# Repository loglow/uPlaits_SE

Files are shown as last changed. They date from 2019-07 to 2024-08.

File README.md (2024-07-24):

# µPlaits SE (uPlaits, microPlaits) Eurorack [Rev C]

## 8HP Eurorack module | Macro-oscillator

[µPlaits SE](http://uplaits-se.com) is a voltage-controlled sound source offering direct access to a large palette of easily tweakable raw sonic material generated by models spanning a wide range of synthesis techniques.

This re-engineered Eurorack module miniaturizes and redesigns the original [Mutable Instruments Plaits](https://mutable-instruments.net/modules/plaits/), reducing its size from 12HP to 8HP and reworking its front panel layout.

Fully compatible with upstream Plaits firmware. Includes power cable, mounting hardware, and a one-year warranty. Designed and built with care by [Tall Dog Electronics](http://tall-dog.com) in Western Massachusetts. Licensed [CC BY-SA 4.0](https://creativecommons.org/licenses/by-sa/4.0/) open source hardware.

- **Height:** 3U (128.5 mm)
- **Width:** 8HP (40.3 mm)
- **Depth:** 43 mm (with power)
- **+12V:** 50 mA (average)
- **-12V:** 5 mA (average)

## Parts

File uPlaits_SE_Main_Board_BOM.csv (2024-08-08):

Ref | Qty | Desc | Mfg | MPN
C1 C2 C3 C4 C8 C9 C32 C35 | 8 | CAP CER 1000PF 50V C0G/NP0 0603 | Murata Electronics | GRM1885C1H102JA01D
C5 C10 C11 C13 C14 C15 C16 C18 C19 C22 C25 C27 C28 C29 C30 C31 C34 C37 C39 C41 C43 C47 | 22 | CAP CER 0.1UF 25V X7R 0603 | Murata Electronics | GCM188R71E104KA57D
C6 C7 C33 C36 | 4 | CAP CER 100PF 50V C0G/NP0 0603 | Vishay Vitramon | VJ0603A101JXACW1BC
C12 C42 C44 C46 C50 | 5 | CAP ALUM 10UF 20% 25V SMD | Würth Elektronik | 865230440002
C17 C21 C24 C26 C48 | 5 | CAP CER 1UF 25V X5R 0603 | YAGEO | CC0603KRX5R8BB105
C20 C23 | 2 | CAP CER 20PF 50V C0G/NP0 0603 | Samsung Electro-Mechanics | CL10C200JB8NNNC
C38 C40 | 2 | CAP CER 2.2UF 25V X5R 0805 | Samsung Electro-Mechanics | CL21A225KAFNNNG
C45 C52 | 2 | CAP ALUM 22UF 20% 25V SMD | Würth Elektronik | 865230443003
C49 C51 C53 | 3 | CAP CER 22UF 25V X5R 1206 | Samsung Electro-Mechanics | CL31A226KAHNNNE
D1 D2 D3 D4 D5 D6 D7 D8 | 8 | VARISTOR 65V 0603 | EPCOS - TDK Electronics | B72500D0160H060
D9 | 1 | DIODE ARR SCHOTT 30V 200MA SOT23 | onsemi | BAT54SLT1G
D10 D11 | 2 | DIODE SCHOTTKY 40V 1A SOD123 | Diodes Incorporated | 1N5819HW-7-F
H1 H2 H3 H4 H5 | 5 | FEMALE HEADER VERTICAL THROUGH H | SUPERIOR TECH | FHMD-DA010G1NBON-B
H6 | 1 | DO NOT POPULATE | DNP | DNP
H7 | 1 | CONN HEADER VERT 10POS 1.27MM | CNC Tech | 3220-10-0100-00
H8 | 1 | CONN HEADER VERT 10POS 2.54MM | On Shore Technology Inc. | 302-S101
L1 L2 L3 L5 | 4 | FERRITE BEAD 1K OHM 0603 1LN | Würth Elektronik | 742792664
L4 | 1 | FIXED IND 33UH 190MA 2.6 OHM SMD | TDK Corporation | MLZ2012M330WT000
R1 R6 R7 R12 R13 R18 R19 R24 | 8 | RES SMD 100K OHM 1% 1/10W 0603 | Panasonic Electronic Components | ERJ-3EKF1003V
R2 R8 R23 | 3 | RES SMD 120K OHM 1% 1/10W 0603 | Panasonic Electronic Components | ERJ-3EKF1203V
R3 R9 R22 | 3 | RES SMD 20K OHM 1% 1/10W 0603 | Panasonic Electronic Components | ERJ-3EKF2002V
R4 R10 R16 R21 R39 R42 | 6 | RES SMD 33K OHM 1% 1/10W 0603 | Panasonic Electronic Components | ERJ-3EKF3302V
R5 R14 R17 | 3 | RES SMD 200K OHM 1% 1/10W 0603 | Panasonic Electronic Components | ERJ-3EKF2003V
R11 | 1 | RES SMD 140K OHM 1% 1/10W 0603 | Panasonic Electronic Components | ERJ-3EKF1403V
R15 | 1 | RES SMD 56K OHM 1% 1/10W 0603 | Panasonic Electronic Components | ERJ-3EKF5602V
R20 | 1 | RES SMD 110K OHM 1% 1/10W 0603 | Panasonic Electronic Components | ERJ-3EKF1103V
R25 R27 R28 R29 R30 R31 R33 R38 R41 | 9 | RES SMD 10K OHM 1% 1/10W 0603 | Panasonic Electronic Components | ERJ-3EKF1002V
R26 R32 R34 R35 | 4 | RES SMD 100 OHM 1% 1/10W 0603 | Panasonic Electronic Components | ERJ-3EKF1000V
R36 R43 | 2 | RES 1K OHM 1% 1/4W 0603 | Rohm Semiconductor | ESR03EZPF1001
R37 R40 R44 | 3 | RES SMD 2.2K OHM 1% 1/10W 0603 | Panasonic Electronic Components | ERJ-3EKF2201V
U1 U2 | 2 | IC OPAMP GP 4 CIRCUIT 14TSSOP | Microchip Technology | MCP6004T-I/ST
U3 | 1 | IC LED DRIVER LINEAR 35MA 24SSOP | Texas Instruments | TLC59281DBQR
U4 | 1 | IC MCU 32BIT 256KB FLASH 48LQFP | STMicroelectronics | STM32F373CCT6
U5 | 1 | IC OPAMP JFET 2 CIRCUIT 8SOIC | Texas Instruments | TL072CDR
U6 | 1 | IC DAC 16/24/32BIT 384K 20TSSOP | Texas Instruments | PCM5100APWR
U7 | 1 | IC VREF SHUNT 0.5% SOT23-3 | Texas Instruments | LM4040C10IDBZR
U8 | 1 | IC REG LINEAR 3.3V 100MA SOT23-5 | STMicroelectronics | LD2981ABM33TR
U9 | 1 | DC DC CONVERTER 3.3V 2W | Recom Power | R-78E3.3-0.5
X1 | 1 | CRYSTAL 8.0000MHZ 18PF SMD | Abracon LLC | ABMM2-8.000MHZ-E2-T

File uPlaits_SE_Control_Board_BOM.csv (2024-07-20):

Ref | Qty | Desc | Mfg | MPN
D1 D2 D3 D4 D5 D6 D7 D8 | 8 | LED GREEN/RED DIFF T-3MM TRI T/H | Lumex Opto/Components Inc. | SSL-LX3059IGW-CA
H1 H2 H3 H4 H5 | 5 | CONN HEADER VERT 10POS 2.54MM | Amphenol ICC (FCI) | 67997-210HLF
J1 J2 J3 J4 J5 J6 J7 J8 J9 J10 | 10 | 3.5MM JACK VERTICAL PCB MOUNT | Wenzhou QingPu | WQP-WQP518MA
P1 P2 P3 P5 | 4 | POT 9MM LINEAR B10K WHITE LINE | Song Huei | R0904N-B10K,L-25KQ/LWS
P4 P6 P7 | 3 | POT 9MM LINEAR B10K WHITE LINE CENTER DETENT | Song Huei | R0904N-B10K,L-25KQ/LWS/CC
S1 S2 | 2 | SWITCH TACTILE SPST-NO 0.05A 12V | E-Switch | TL1105DF160Q

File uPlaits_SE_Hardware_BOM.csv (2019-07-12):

Description | Quantity
Thonkiconn Knurled Nut, Steel, M6 | 10
Threaded Hex Standoff, Brass, M2.5 x 11 mm | 2
Standoff Screw, Button Head, Hex Socket, M2.5 x 6 mm | 4

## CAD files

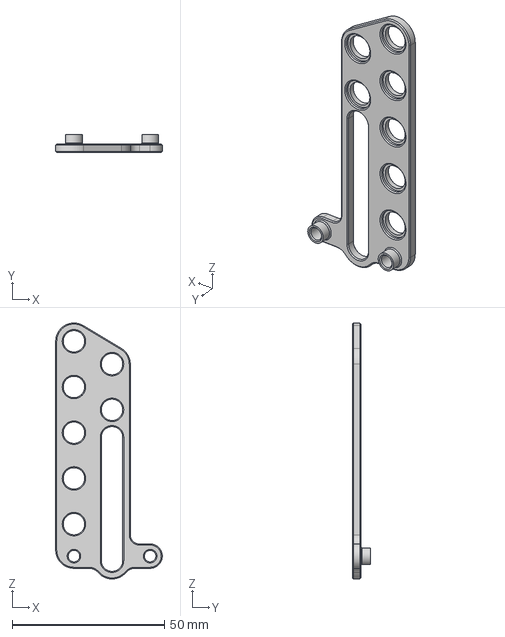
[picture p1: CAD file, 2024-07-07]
uPlaits_SE_Assembly_Spacer.step
35.0 x 6.00 x 84.0 mm

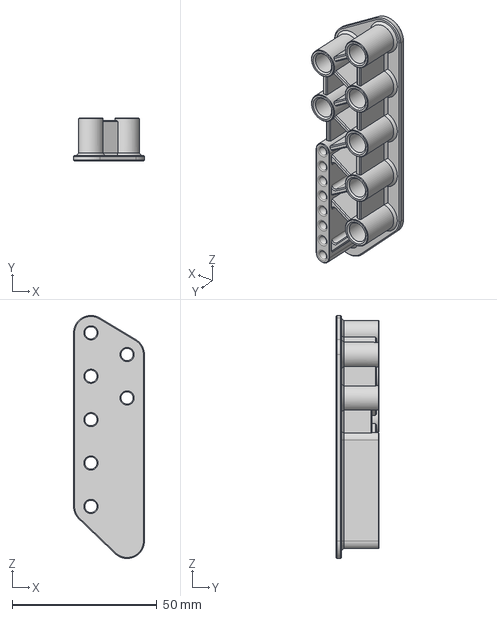
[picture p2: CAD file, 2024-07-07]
uPlaits_SE_Assembly_Cap.step
24.5 x 15.0 x 84.0 mm

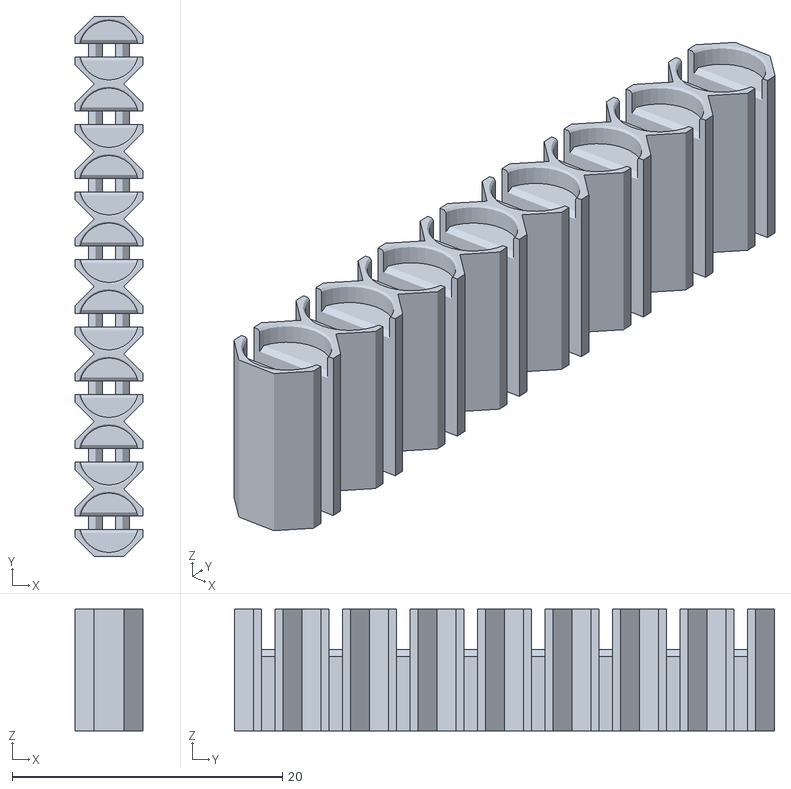
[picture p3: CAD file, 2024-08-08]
uPlaits_SE_LED_Spacer.stl
5.00 x 40.0 x 9.00

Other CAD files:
uPlaits_SE_Assembly_Cap.stl
uPlaits_SE_Assembly_Spacer.stl
uPlaits_SE_Model.skp

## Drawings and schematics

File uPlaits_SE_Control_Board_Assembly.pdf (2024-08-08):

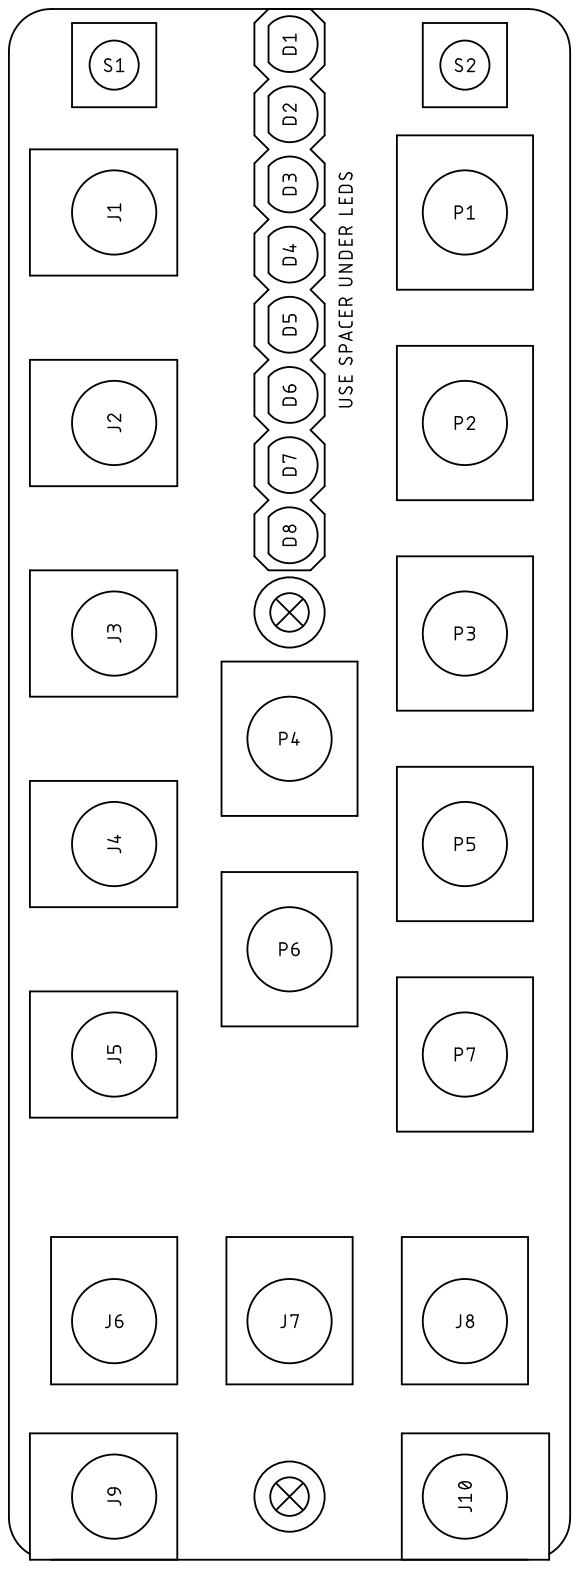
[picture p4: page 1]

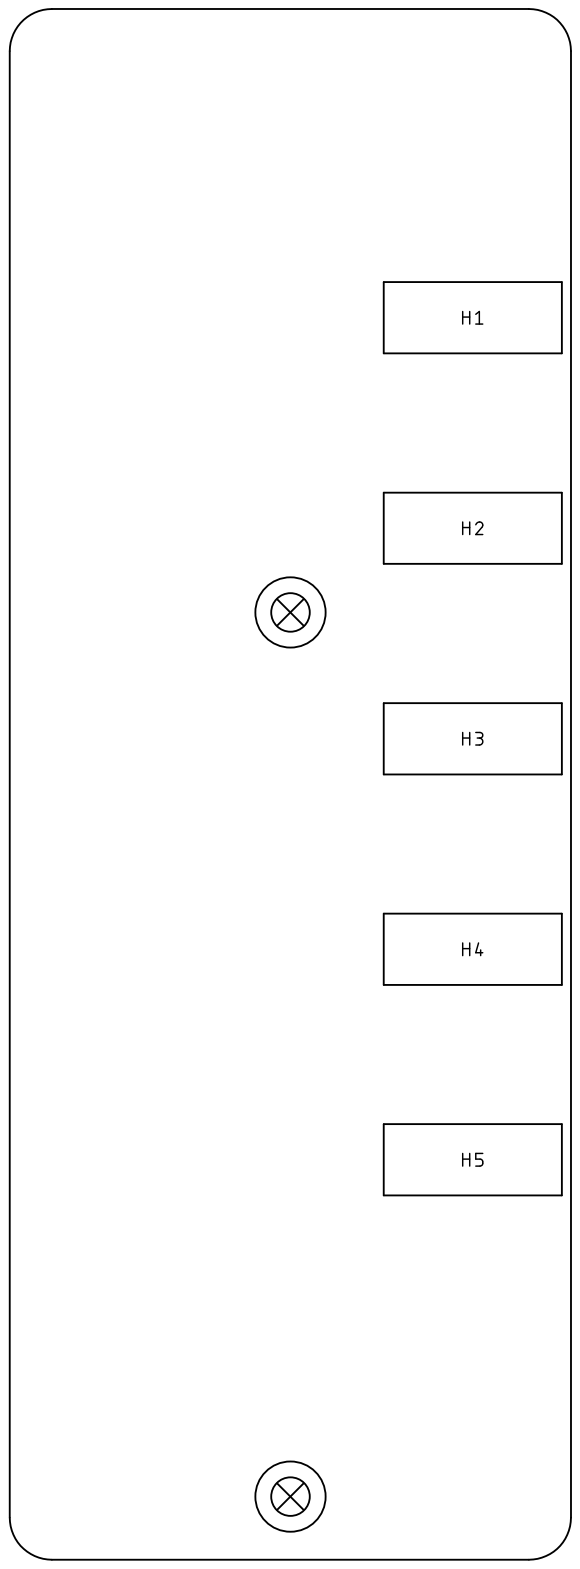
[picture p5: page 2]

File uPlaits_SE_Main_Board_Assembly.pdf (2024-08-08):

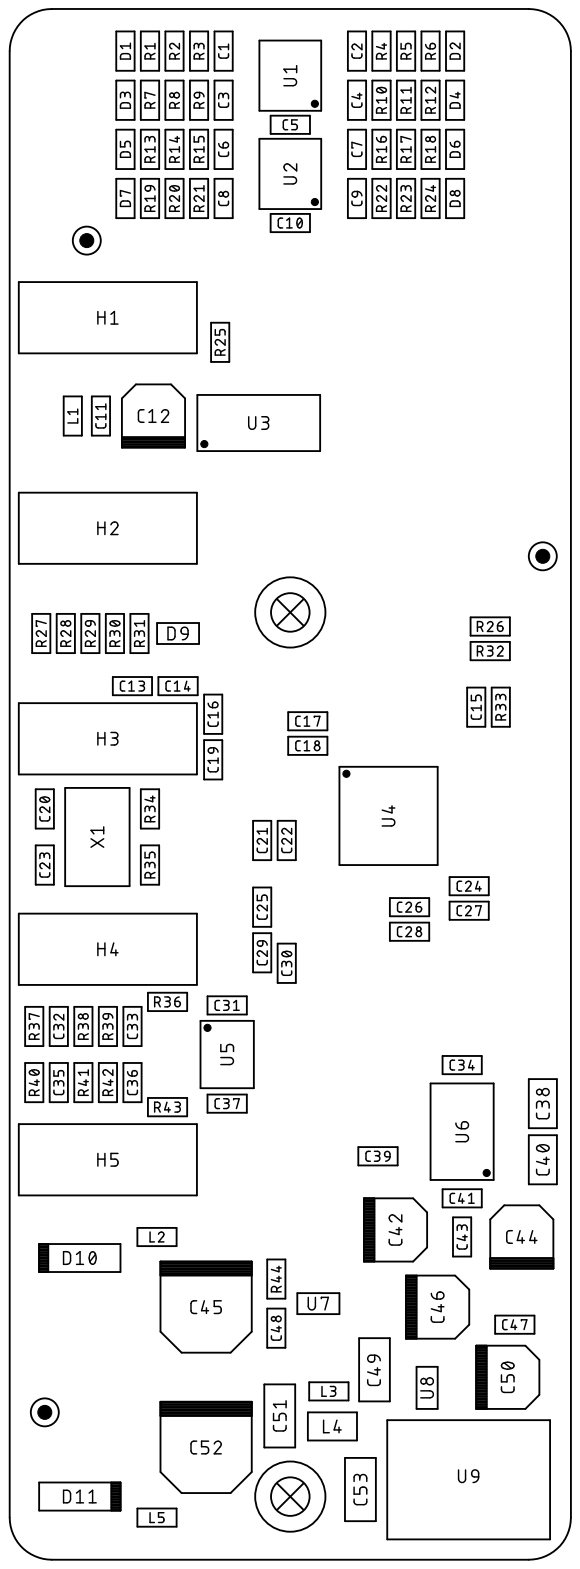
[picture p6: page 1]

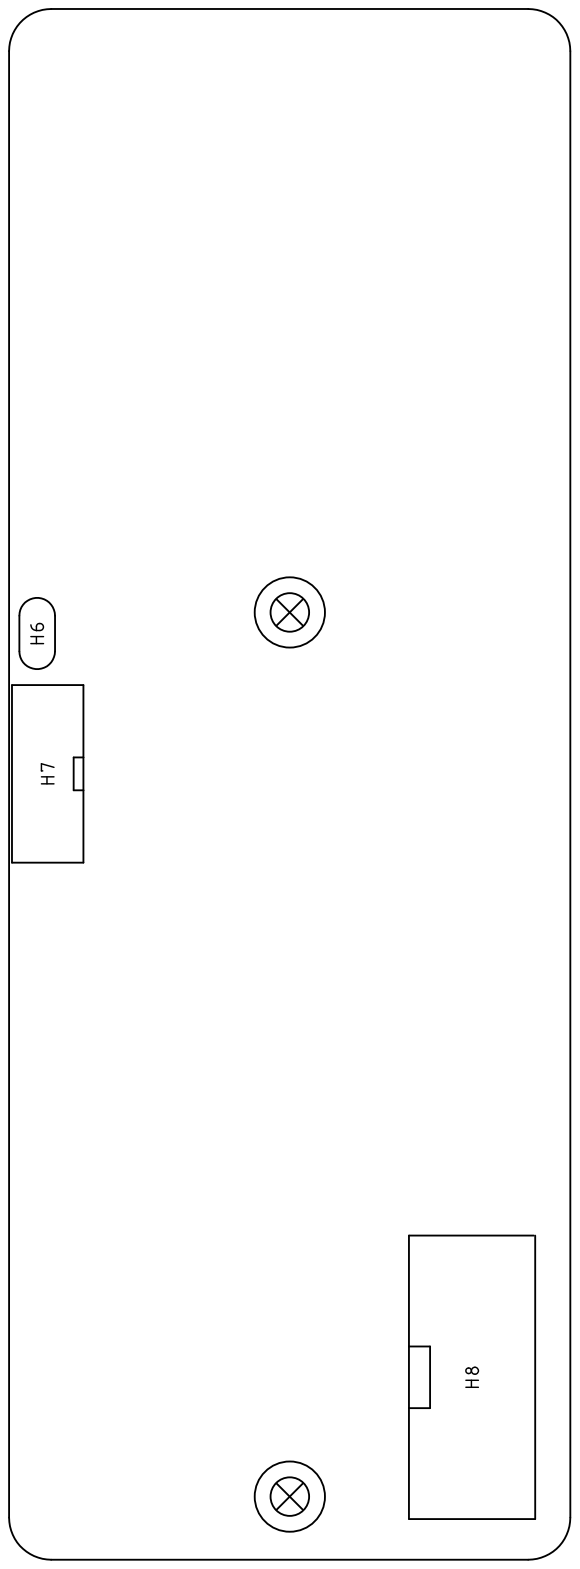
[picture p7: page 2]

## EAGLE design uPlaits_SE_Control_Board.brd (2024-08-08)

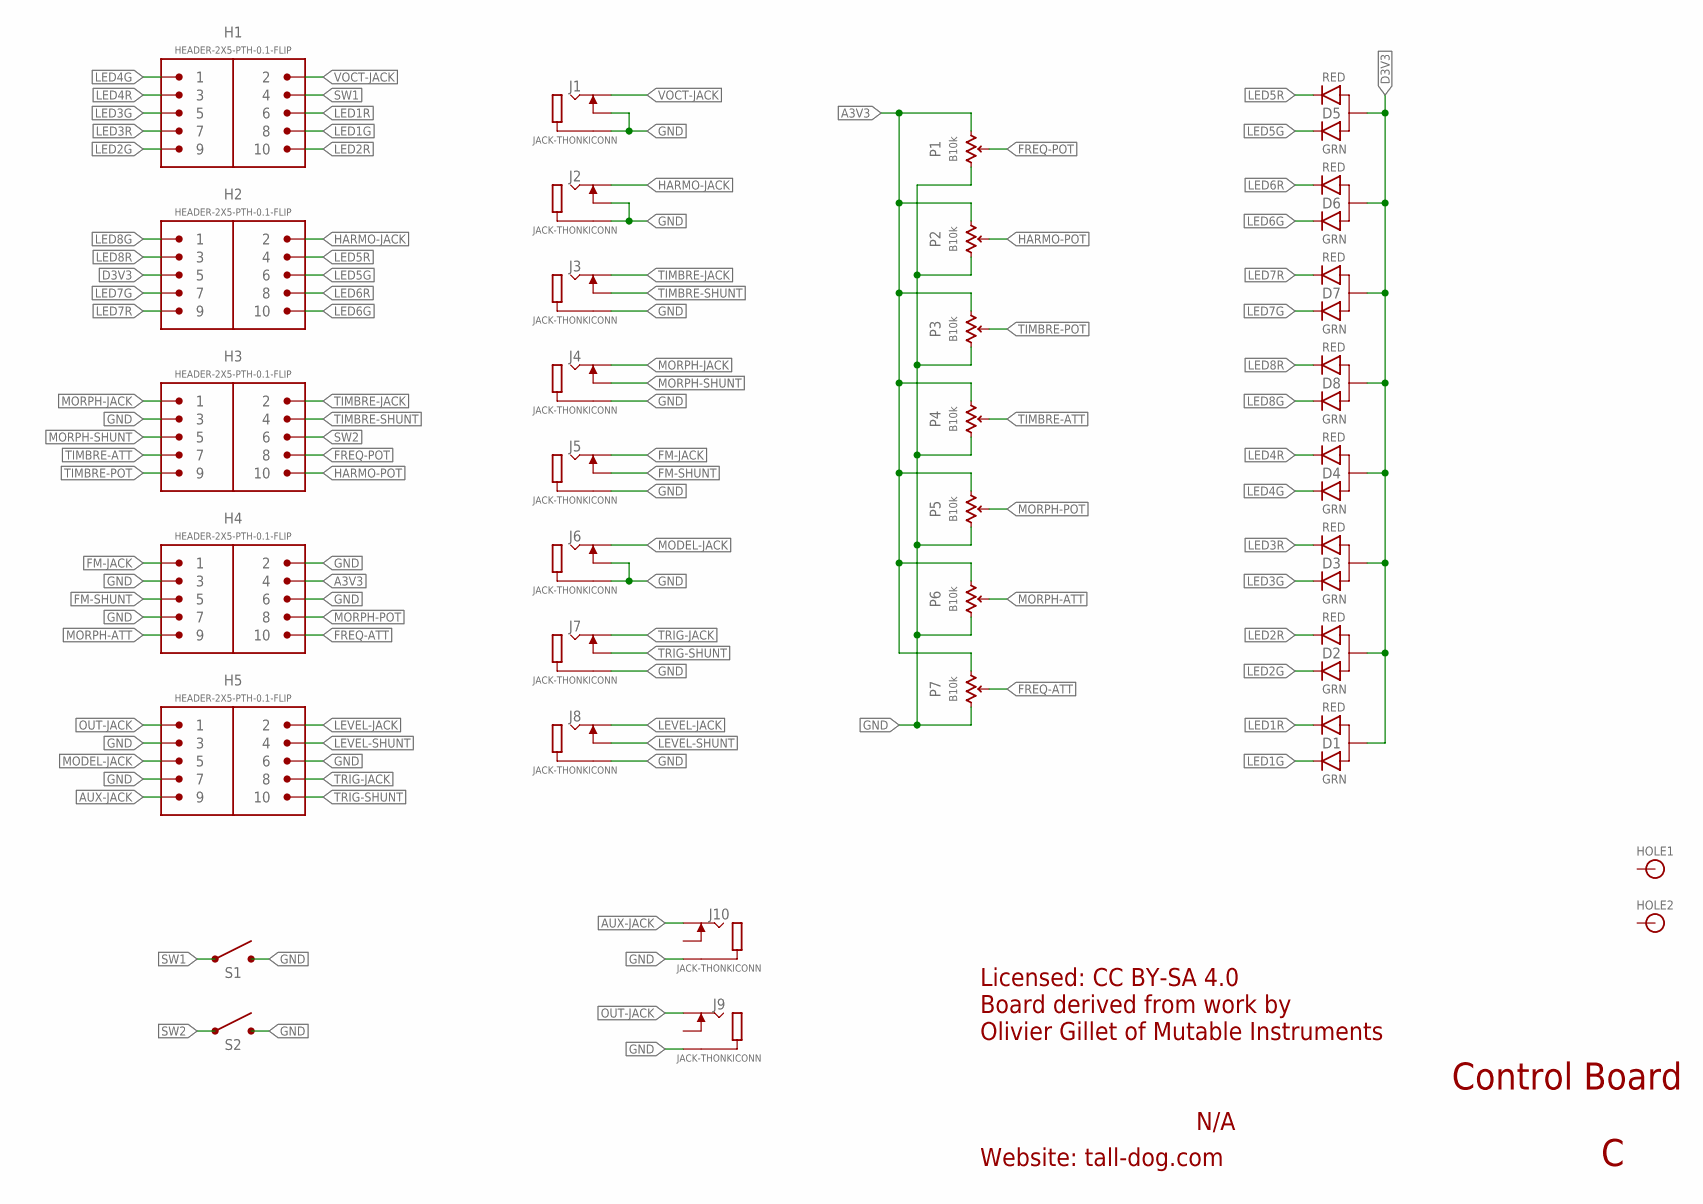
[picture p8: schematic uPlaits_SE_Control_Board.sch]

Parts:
D1, D2, D3, D4, D5, D6, D7, D8: LED-DUAL-PTH; LED-T1-3
H1, H2, H3, H4, H5: HEADER-2X5-PTH-0.1-FLIP; PTH-0.1-2X5-FLIP
HOLE1, HOLE2: HOLE; HOLE-M2.5
J1, J2, J3, J4, J5, J6, J7, J8, J9, J10: JACK-THONKICONN; THONKICONN
P1, P2, P3, P4, P5, P6, P7: B10k; POT-SONG-9MM
S1, S2: SPST-PTH; TL1105

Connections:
A3V3: H4.4, P1.P$1 (E), P2.P$1 (E), P3.P$1 (E), P4.P$1 (E), P5.P$1 (E), P6.P$1 (E), P7.P$1 (E)
AUX-JACK: H5.9, J10.P3 (3)
D3V3: D1.2 (A), D2.2 (A), D3.2 (A), D4.2 (A), D5.2 (A), D6.2 (A), D7.2 (A), D8.2 (A), H2.5
FM-JACK: H4.1, J5.P3 (3)
FM-SHUNT: H4.5, J5.P2 (2)
FREQ-ATT: H4.10, P7.P$2 (S)
FREQ-POT: H3.8, P1.P$2 (S)
GND: H3.3, H4.2, H4.3, H4.6, H4.7, H5.3, H5.6, H5.7, J1.P1 (1), J1.P2 (2), J2.P1 (1), J2.P2 (2), J3.P1 (1), J4.P1 (1), J5.P1 (1), J6.P1 (1), J6.P2 (2), J7.P1 (1), J8.P1 (1), J9.P1 (1), J10.P1 (1), P1.P$3 (A), P2.P$3 (A), P3.P$3 (A), P4.P$3 (A), P5.P$3 (A), P6.P$3 (A), P7.P$3 (A), S1.3 (2), S1.4 (2), S2.3 (2), S2.4 (2)
HARMO-JACK: H2.2, J2.P3 (3)
HARMO-POT: H3.10, P2.P$2 (S)
LED1G: D1.3 (GRN), H1.8
LED1R: D1.1 (RED), H1.6
LED2G: D2.3 (GRN), H1.9
LED2R: D2.1 (RED), H1.10
LED3G: D3.3 (GRN), H1.5
LED3R: D3.1 (RED), H1.7
LED4G: D4.3 (GRN), H1.1
LED4R: D4.1 (RED), H1.3
LED5G: D5.3 (GRN), H2.6
LED5R: D5.1 (RED), H2.4
LED6G: D6.3 (GRN), H2.10
LED6R: D6.1 (RED), H2.8
LED7G: D7.3 (GRN), H2.7
LED7R: D7.1 (RED), H2.9
LED8G: D8.3 (GRN), H2.1
LED8R: D8.1 (RED), H2.3
LEVEL-JACK: H5.2, J8.P3 (3)
LEVEL-SHUNT: H5.4, J8.P2 (2)
MODEL-JACK: H5.5, J6.P3 (3)
MORPH-ATT: H4.9, P6.P$2 (S)
MORPH-JACK: H3.1, J4.P3 (3)
MORPH-POT: H4.8, P5.P$2 (S)
MORPH-SHUNT: H3.5, J4.P2 (2)
OUT-JACK: H5.1, J9.P3 (3)
SW1: H1.4, S1.1, S1.2 (1)
SW2: H3.6, S2.1, S2.2 (1)
TIMBRE-ATT: H3.7, P4.P$2 (S)
TIMBRE-JACK: H3.2, J3.P3 (3)
TIMBRE-POT: H3.9, P3.P$2 (S)
TIMBRE-SHUNT: H3.4, J3.P2 (2)
TRIG-JACK: H5.8, J7.P3 (3)
TRIG-SHUNT: H5.10, J7.P2 (2)
VOCT-JACK: H1.2, J1.P3 (3)

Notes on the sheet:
Licensed: CC BY-SA 4.0 Board derived from work by Olivier Gillet of Mutable Instruments
Website: tall-dog.com
N/A
Control Board

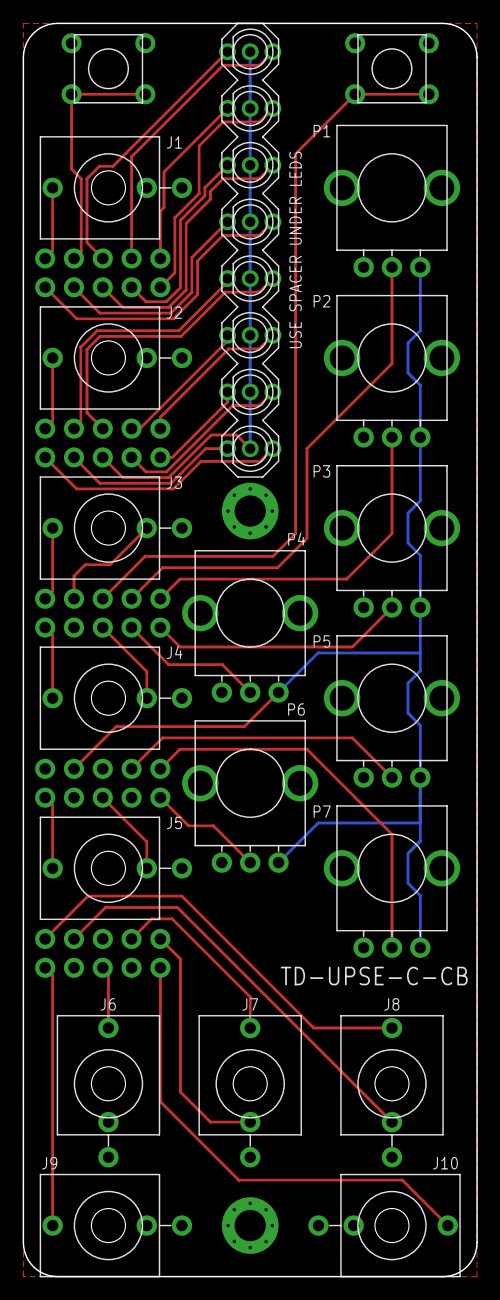
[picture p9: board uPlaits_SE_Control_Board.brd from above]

Board: 2 copper layers, 40.0 x 110.5 mm, 35 parts (0 on the bottom side), 43 nets.

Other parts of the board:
U$1: LED-SPACER

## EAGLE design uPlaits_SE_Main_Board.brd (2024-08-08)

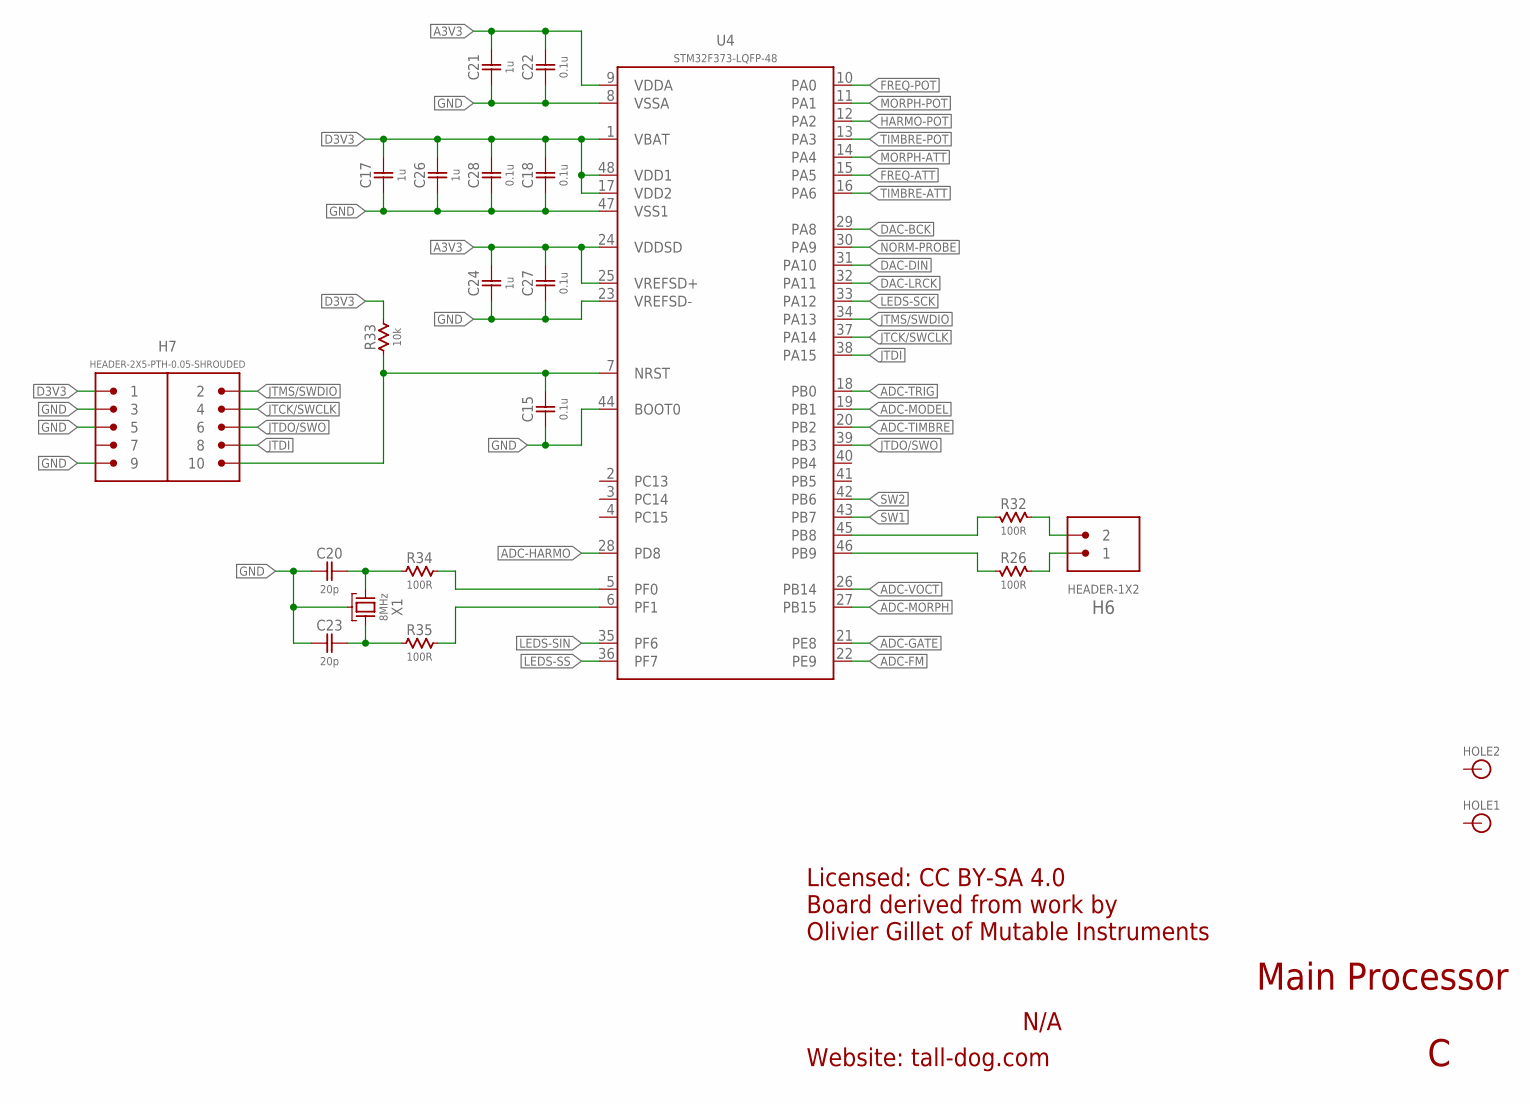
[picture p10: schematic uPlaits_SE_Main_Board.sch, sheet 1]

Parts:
C15, C18, C22, C27, C28: 0.1u; 0603-NP
C17, C21, C24, C26: 1u; 0603-NP
C20, C23: 20p; 0603-NP
H6: HEADER-1X2; PTH-0.1-1X2
H7: HEADER-2X5-PTH-0.05-SHROUDED; PTH-0.05-2X5-SHROUDED
HOLE1, HOLE2: HOLE; HOLE-M2.5
R26, R32, R34, R35: 100R; 0603-NP
R33: 10k; 0603-NP
U4: STM32F373-LQFP-48; LQFP-48
X1: 8MHz; CRYSTAL-ABMM2

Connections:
A3V3: C21.2, C22.2, C24.2, C27.2, U4.9 (VDDA), U4.24 (VDDSD), U4.25 (VREFSD+); also elsewhere on the board
ADC-FM: U4.22 (PE9); also elsewhere on the board
ADC-GATE: U4.21 (PE8); also elsewhere on the board
ADC-HARMO: U4.28 (PD8); also elsewhere on the board
ADC-MODEL: U4.19 (PB1); also elsewhere on the board
ADC-MORPH: U4.27 (PB15); also elsewhere on the board
ADC-TIMBRE: U4.20 (PB2); also elsewhere on the board
ADC-TRIG: U4.18 (PB0); also elsewhere on the board
ADC-VOCT: U4.26 (PB14); also elsewhere on the board
D3V3: C17.2, C18.2, C26.2, C28.2, H7.1, R33.2, U4.1 (VBAT), U4.17 (VDD2), U4.48 (VDD1); also elsewhere on the board
DAC-BCK: U4.29 (PA8); also elsewhere on the board
DAC-DIN: U4.31 (PA10); also elsewhere on the board
DAC-LRCK: U4.32 (PA11); also elsewhere on the board
FREQ-ATT: U4.15 (PA5); also elsewhere on the board
FREQ-POT: U4.10 (PA0); also elsewhere on the board
GND: C15.1, C17.1, C18.1, C20.1, C21.1, C22.1, C23.1, C24.1, C26.1, C27.1, C28.1, H7.3, H7.5, H7.9, U4.8 (VSSA), U4.23 (VREFSD-), U4.44 (BOOT0), U4.47 (VSS1), X1.2 (G), X1.4 (G); also elsewhere on the board
HARMO-POT: U4.12 (PA2); also elsewhere on the board
JTCK/SWCLK: H7.4, U4.37 (PA14)
JTDI: H7.8, U4.38 (PA15)
JTDO/SWO: H7.6, U4.39 (PB3)
JTMS/SWDIO: H7.2, U4.34 (PA13)
LEDS-SCK: U4.33 (PA12); also elsewhere on the board
LEDS-SIN: U4.35 (PF6); also elsewhere on the board
LEDS-SS: U4.36 (PF7); also elsewhere on the board
MORPH-ATT: U4.14 (PA4); also elsewhere on the board
MORPH-POT: U4.11 (PA1); also elsewhere on the board
unnamed: C20.2, R34.1, X1.3 (2)
unnamed: C23.2, R35.1, X1.1
unnamed: R34.2, U4.5 (PF0)
unnamed: R35.2, U4.6 (PF1)
NORM-PROBE: U4.30 (PA9); also elsewhere on the board
RESET: C15.2, H7.10, R33.1, U4.7 (NRST)
RX: H6.1, R26.1
RX1: R26.2, U4.46 (PB9)
SW1: U4.43 (PB7); also elsewhere on the board
SW2: U4.42 (PB6); also elsewhere on the board
TIMBRE-ATT: U4.16 (PA6); also elsewhere on the board
TIMBRE-POT: U4.13 (PA3); also elsewhere on the board
TX: H6.2, R32.1
TX1: R32.2, U4.45 (PB8)

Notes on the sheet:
Licensed: CC BY-SA 4.0 Board derived from work by Olivier Gillet of Mutable Instruments
Website: tall-dog.com
N/A
Main Processor

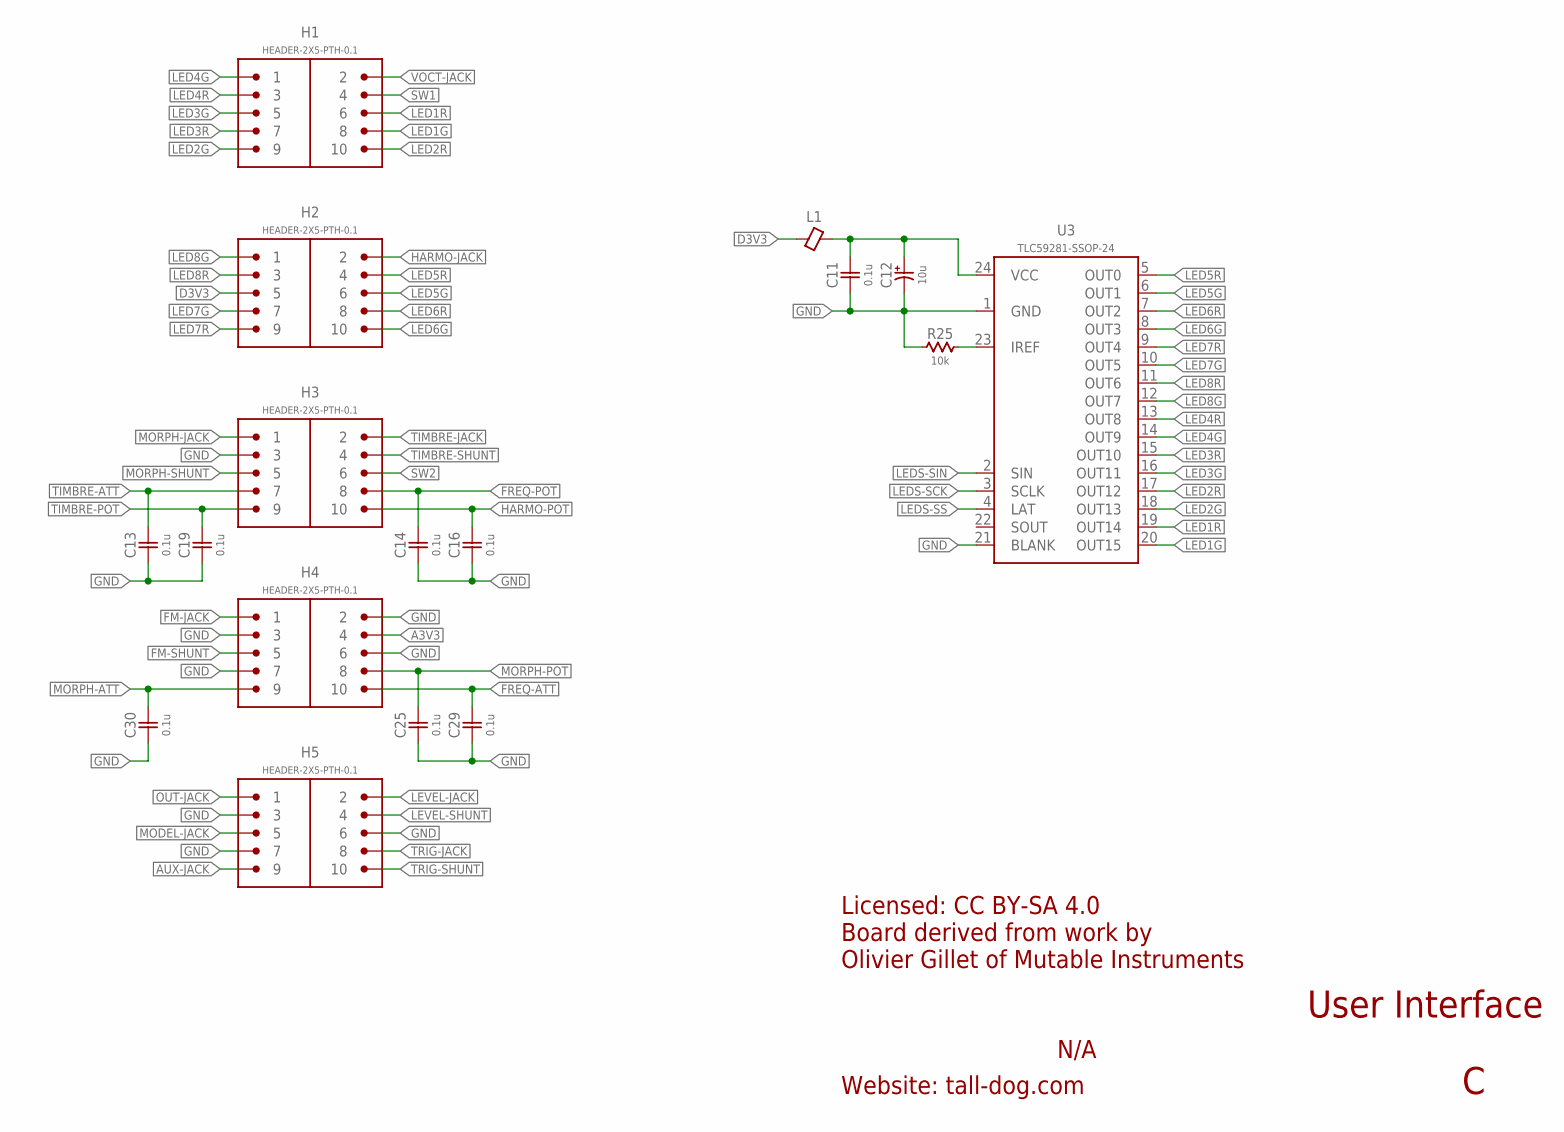
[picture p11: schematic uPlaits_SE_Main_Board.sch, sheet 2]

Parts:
C11, C13, C14, C16, C19, C25, C29, C30: 0.1u; 0603-NP
C12: 10u; ELECTRO-SMD-4.3MM
H1, H2, H3, H4, H5: HEADER-2X5-PTH-0.1; PTH-0.1-2X5
L1: FERRITE-BEAD-0603; 0603-NP
R25: 10k; 0603-NP
U3: TLC59281-SSOP-24; SSOP-24

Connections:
A3V3: H4.4; also elsewhere on the board
AUX-JACK: H5.9; also elsewhere on the board
D3V3: H2.5, L1.1; also elsewhere on the board
FM-JACK: H4.1; also elsewhere on the board
FM-SHUNT: H4.5; also elsewhere on the board
FREQ-ATT: C29.2, H4.10; also elsewhere on the board
FREQ-POT: C14.2, H3.8; also elsewhere on the board
GND: C11.1, C12.C (NEG), C13.1, C14.1, C16.1, C19.1, C25.1, C29.1, C30.1, H3.3, H4.2, H4.3, H4.6, H4.7, H5.3, H5.6, H5.7, R25.1, U3.1 (GND), U3.21 (BLANK); also elsewhere on the board
HARMO-JACK: H2.2; also elsewhere on the board
HARMO-POT: C16.2, H3.10; also elsewhere on the board
IREF: R25.2, U3.23 (IREF)
LED1G: H1.8, U3.20 (OUT15)
LED1R: H1.6, U3.19 (OUT14)
LED2G: H1.9, U3.18 (OUT13)
LED2R: H1.10, U3.17 (OUT12)
LED3G: H1.5, U3.16 (OUT11)
LED3R: H1.7, U3.15 (OUT10)
LED4G: H1.1, U3.14 (OUT9)
LED4R: H1.3, U3.13 (OUT8)
LED5G: H2.6, U3.6 (OUT1)
LED5R: H2.4, U3.5 (OUT0)
LED6G: H2.10, U3.8 (OUT3)
LED6R: H2.8, U3.7 (OUT2)
LED7G: H2.7, U3.10 (OUT5)
LED7R: H2.9, U3.9 (OUT4)
LED8G: H2.1, U3.12 (OUT7)
LED8R: H2.3, U3.11 (OUT6)
LEDS-SCK: U3.3 (SCLK); also elsewhere on the board
LEDS-SIN: U3.2 (SIN); also elsewhere on the board
LEDS-SS: U3.4 (LAT); also elsewhere on the board
LEVEL-JACK: H5.2; also elsewhere on the board
LEVEL-SHUNT: H5.4; also elsewhere on the board
MODEL-JACK: H5.5; also elsewhere on the board
MORPH-ATT: C30.2, H4.9; also elsewhere on the board
MORPH-JACK: H3.1; also elsewhere on the board
MORPH-POT: C25.2, H4.8; also elsewhere on the board
MORPH-SHUNT: H3.5; also elsewhere on the board
unnamed: C11.2, C12.A (POS), L1.2, U3.24 (VCC)
OUT-JACK: H5.1; also elsewhere on the board
SW1: H1.4; also elsewhere on the board
SW2: H3.6; also elsewhere on the board
TIMBRE-ATT: C13.2, H3.7; also elsewhere on the board
TIMBRE-JACK: H3.2; also elsewhere on the board
TIMBRE-POT: C19.2, H3.9; also elsewhere on the board
TIMBRE-SHUNT: H3.4; also elsewhere on the board
TRIG-JACK: H5.8; also elsewhere on the board
TRIG-SHUNT: H5.10; also elsewhere on the board
VOCT-JACK: H1.2; also elsewhere on the board

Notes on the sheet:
Licensed: CC BY-SA 4.0 Board derived from work by Olivier Gillet of Mutable Instruments
Website: tall-dog.com
N/A
User Interface

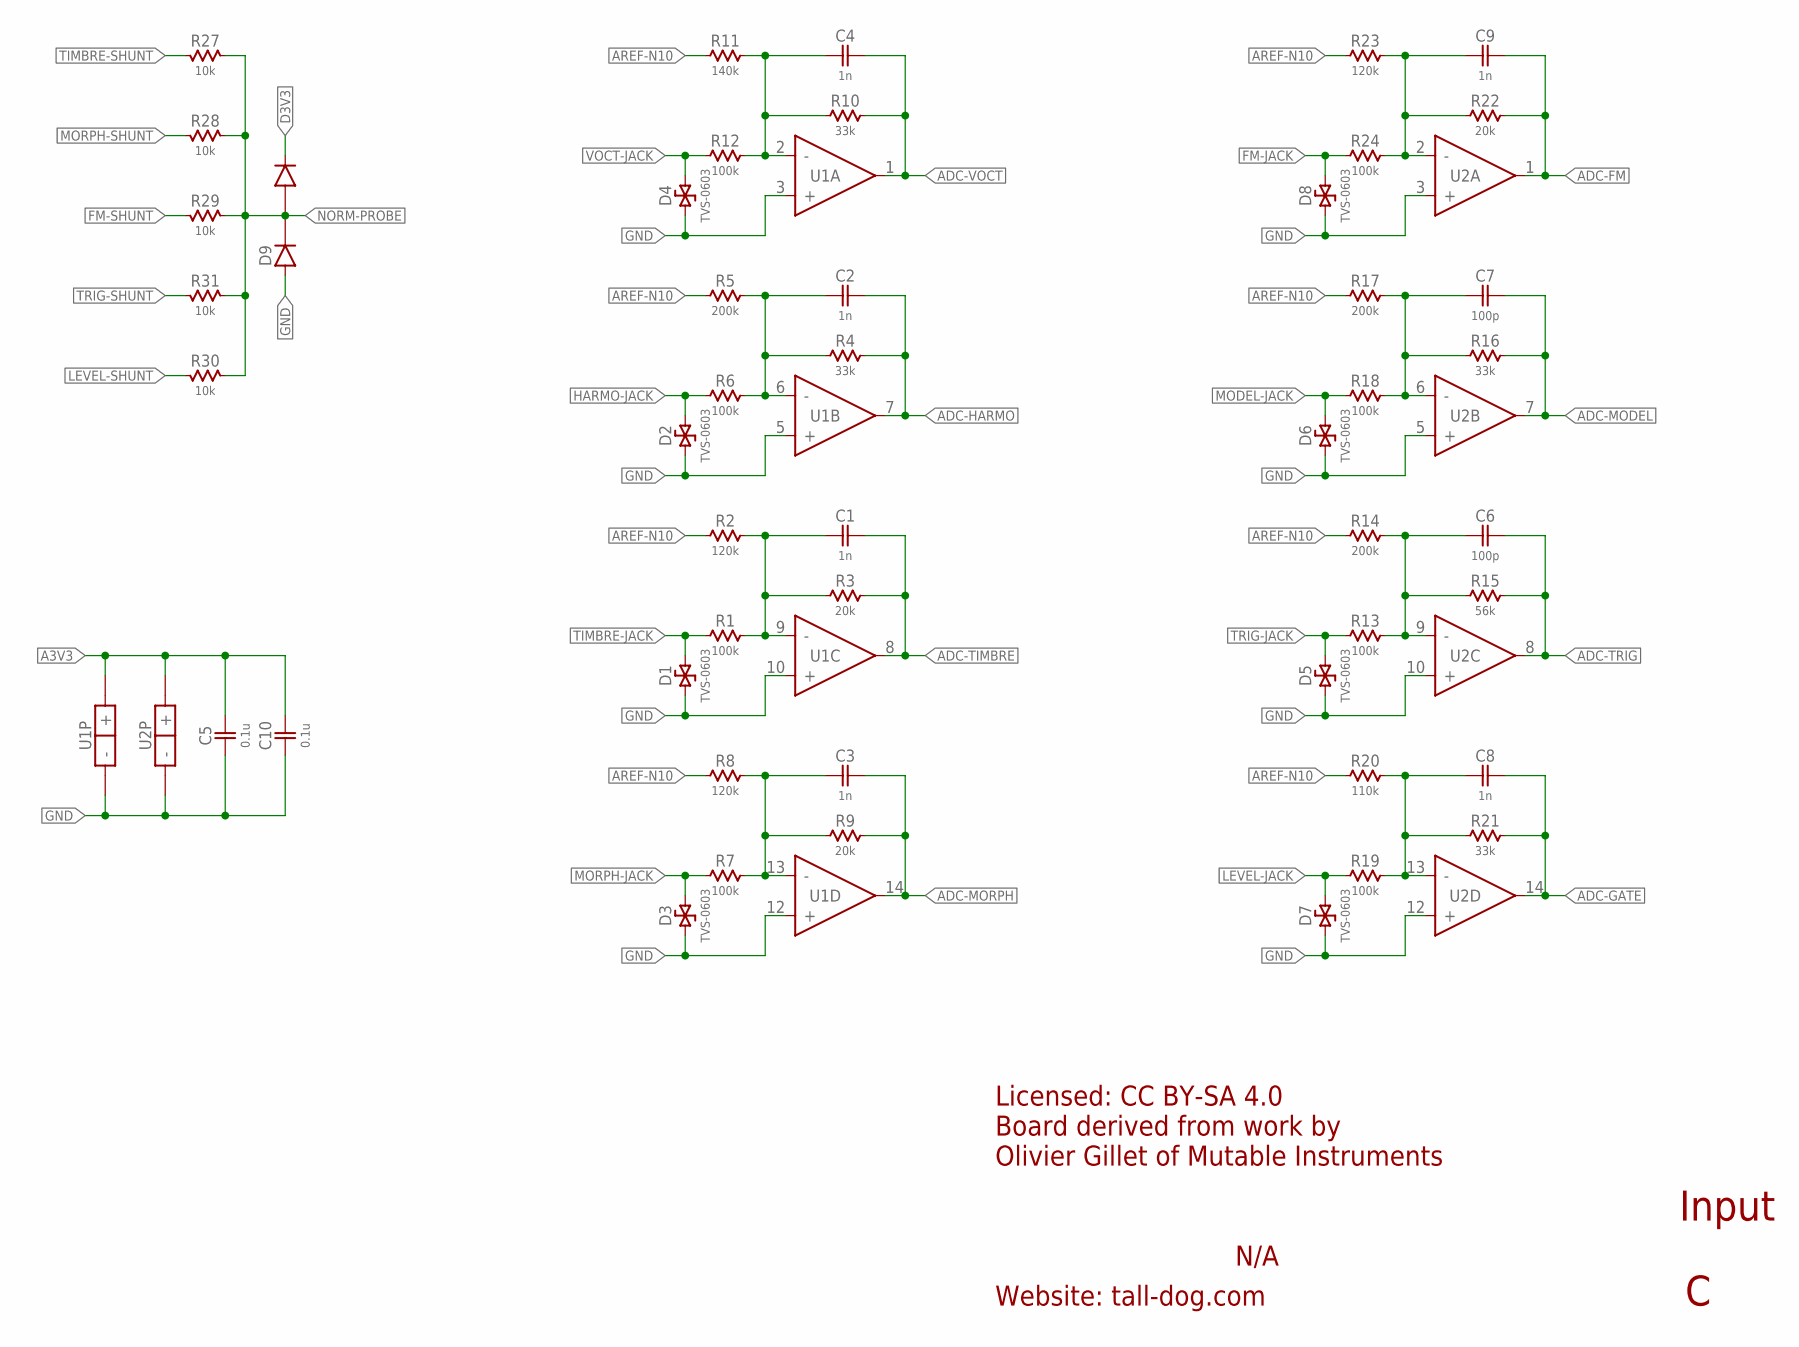
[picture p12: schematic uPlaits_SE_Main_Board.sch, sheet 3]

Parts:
C1, C2, C3, C4, C8, C9: 1n; 0603-NP
C5, C10: 0.1u; 0603-NP
C6, C7: 100p; 0603-NP
D1, D2, D3, D4, D5, D6, D7, D8: TVS-0603; 0603-NP
D9: DIODE-DUAL-SOT-23; SOT-23-3
R1, R6, R7, R12, R13, R18, R19, R24: 100k; 0603-NP
R2, R8, R23: 120k; 0603-NP
R3, R9, R22: 20k; 0603-NP
R4, R10, R16, R21: 33k; 0603-NP
R5, R14, R17: 200k; 0603-NP
R11: 140k; 0603-NP
R15: 56k; 0603-NP
R20: 110k; 0603-NP
R27, R28, R29, R30, R31: 10k; 0603-NP
U1, U2: MCP6004-TSSOP-14; TSSOP-14

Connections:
A3V3: C5.2, C10.2, U1.4 (+), U2.4 (+); also elsewhere on the board
ADC-FM: C9.2, R22.2, U2.1 (OUT); also elsewhere on the board
ADC-GATE: C8.2, R21.2, U2.14 (OUT); also elsewhere on the board
ADC-HARMO: C2.2, R4.2, U1.7 (OUT); also elsewhere on the board
ADC-MODEL: C7.2, R16.2, U2.7 (OUT); also elsewhere on the board
ADC-MORPH: C3.2, R9.2, U1.14 (OUT); also elsewhere on the board
ADC-TIMBRE: C1.2, R3.2, U1.8 (OUT); also elsewhere on the board
ADC-TRIG: C6.2, R15.2, U2.8 (OUT); also elsewhere on the board
ADC-VOCT: C4.2, R10.2, U1.1 (OUT); also elsewhere on the board
AREF-N10: R2.1, R5.1, R8.1, R11.1, R14.1, R17.1, R20.1, R23.1; also elsewhere on the board
D3V3: D9.2 (C2); also elsewhere on the board
FM-JACK: D8.2, R24.1; also elsewhere on the board
FM-SHUNT: R29.2; also elsewhere on the board
GND: C5.1, C10.1, D1.1, D2.1, D3.1, D4.1, D5.1, D6.1, D7.1, D8.1, D9.1 (A1), U1.3 (+), U1.5 (+), U1.10 (+), U1.11 (-), U1.12 (+), U2.3 (+), U2.5 (+), U2.10 (+), U2.11 (-), U2.12 (+); also elsewhere on the board
HARMO-JACK: D2.2, R6.1; also elsewhere on the board
LEVEL-JACK: D7.2, R19.1; also elsewhere on the board
LEVEL-SHUNT: R30.2; also elsewhere on the board
MODEL-JACK: D6.2, R18.1; also elsewhere on the board
MORPH-JACK: D3.2, R7.1; also elsewhere on the board
MORPH-SHUNT: R28.2; also elsewhere on the board
unnamed: C4.1, R10.1, R11.2, R12.2, U1.2 (-)
unnamed: C2.1, R4.1, R5.2, R6.2, U1.6 (-)
unnamed: C9.1, R22.1, R23.2, R24.2, U2.2 (-)
unnamed: C1.1, R1.2, R2.2, R3.1, U1.9 (-)
unnamed: C3.1, R7.2, R8.2, R9.1, U1.13 (-)
unnamed: C7.1, R16.1, R17.2, R18.2, U2.6 (-)
unnamed: C6.1, R13.2, R14.2, R15.1, U2.9 (-)
unnamed: C8.1, R19.2, R20.2, R21.1, U2.13 (-)
NORM-PROBE: D9.3 (C1/A2), R27.1, R28.1, R29.1, R30.1, R31.1; also elsewhere on the board
TIMBRE-JACK: D1.2, R1.1; also elsewhere on the board
TIMBRE-SHUNT: R27.2; also elsewhere on the board
TRIG-JACK: D5.2, R13.1; also elsewhere on the board
TRIG-SHUNT: R31.2; also elsewhere on the board
VOCT-JACK: D4.2, R12.1; also elsewhere on the board

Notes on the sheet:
Licensed: CC BY-SA 4.0 Board derived from work by Olivier Gillet of Mutable Instruments
Website: tall-dog.com
N/A
Input

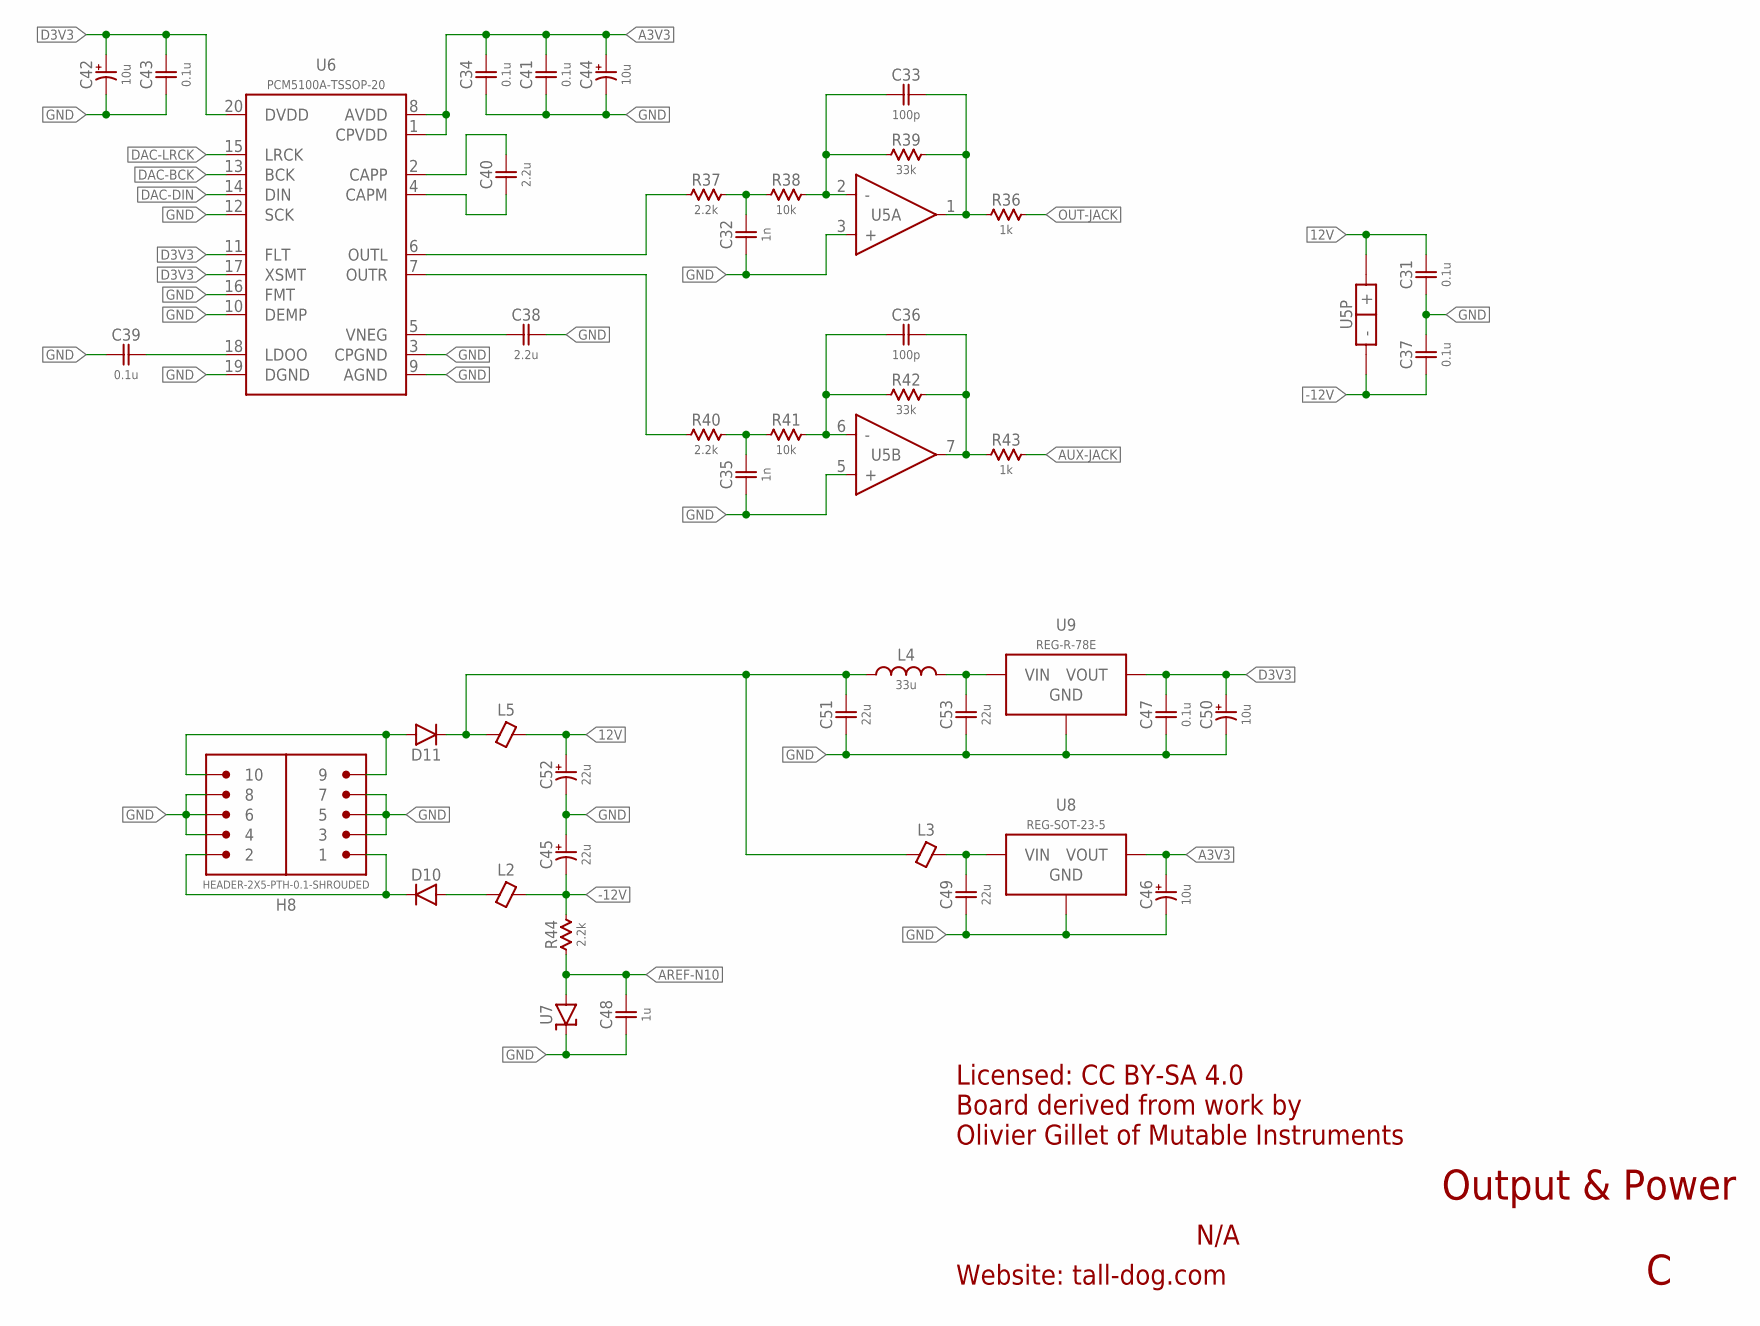
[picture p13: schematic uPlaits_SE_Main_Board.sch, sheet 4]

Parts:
C31, C34, C37, C39, C41, C43, C47: 0.1u; 0603-NP
C32, C35: 1n; 0603-NP
C33, C36: 100p; 0603-NP
C38, C40: 2.2u; 0805-NP
C42, C44, C46, C50: 10u; ELECTRO-SMD-4.3MM
C45, C52: 22u; ELECTRO-SMD-6.6MM
C48: 1u; 0603-NP
C49, C51, C53: 22u; 1206-NP
D10, D11: DIODE-SOD123; SOD-123
H8: HEADER-2X5-PTH-0.1-SHROUDED; PTH-0.1-2X5-SHROUDED
L2, L3, L5: FERRITE-BEAD-0603; 0603-NP
L4: 33u; 0805-NP
R36, R43: 1k; 0603-NP
R37, R40, R44: 2.2k; 0603-NP
R38, R41: 10k; 0603-NP
R39, R42: 33k; 0603-NP
U5: TL072-SO-8; SO-8
U6: PCM5100A-TSSOP-20; TSSOP-20
U7: LM4040-SOT-23; SOT-23-3
U8: REG-SOT-23-5; SOT-23-5
U9: REG-R-78E; R-78E

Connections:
12V: C31.2, C52.A (POS), L5.2, U5.8 (+)
12V-IN: D11.A, H8.9, H8.10
-12V: C37.1, C45.C (NEG), L2.2, R44.2, U5.4 (-)
-12V-IN: D10.C, H8.1, H8.2
A3V3: C34.2, C41.2, C44.A (POS), C46.A (POS), U6.1 (CPVDD), U6.8 (AVDD), U8.5 (VOUT); also elsewhere on the board
AREF-N10: C48.2, R44.1, U7.2 (A); also elsewhere on the board
AUX-JACK: R43.2; also elsewhere on the board
D3V3: C42.A (POS), C43.2, C47.2, C50.A (POS), U6.11 (FLT), U6.17 (XSMT), U6.20 (DVDD), U9.3 (VOUT); also elsewhere on the board
DAC-BCK: U6.13 (BCK); also elsewhere on the board
DAC-DIN: U6.14 (DIN); also elsewhere on the board
DAC-LRCK: U6.15 (LRCK); also elsewhere on the board
GND: C31.1, C32.1, C34.1, C35.1, C37.2, C38.2, C39.1, C41.1, C42.C (NEG), C43.1, C44.C (NEG), C45.A (POS), C46.C (NEG), C47.1, C48.1, C49.1, C50.C (NEG), C51.1, C52.C (NEG), C53.1, H8.3, H8.4, H8.5, H8.6, H8.7, H8.8, U5.3 (+), U5.5 (+), U6.3 (CPGND), U6.9 (AGND), U6.10 (DEMP), U6.12 (SCK), U6.16 (FMT), U6.19 (DGND), U7.1 (C), U8.2 (GND), U9.2 (GND); also elsewhere on the board
unnamed: C32.2, R37.2, R38.1
unnamed: C35.2, R40.2, R41.1
unnamed: C33.1, R38.2, R39.1, U5.2 (-)
unnamed: C36.1, R41.2, R42.1, U5.6 (-)
unnamed: C40.2, U6.2 (CAPP)
unnamed: C40.1, U6.4 (CAPM)
unnamed: R37.1, U6.6 (OUTL)
unnamed: R40.1, U6.7 (OUTR)
unnamed: C38.1, U6.5 (VNEG)
unnamed: D10.A, L2.1
unnamed: C51.2, D11.C, L3.1, L4.1, L5.1
unnamed: C36.2, R42.2, R43.1, U5.7 (OUT)
unnamed: C33.2, R36.1, R39.2, U5.1 (OUT)
unnamed: C53.2, L4.2, U9.1 (VIN)
unnamed: C49.2, L3.2, U8.1 (VIN), U8.3 (VIN)
unnamed: C39.2, U6.18 (LDOO)
OUT-JACK: R36.2; also elsewhere on the board

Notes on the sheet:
Licensed: CC BY-SA 4.0 Board derived from work by Olivier Gillet of Mutable Instruments
Website: tall-dog.com
N/A
Output & Power

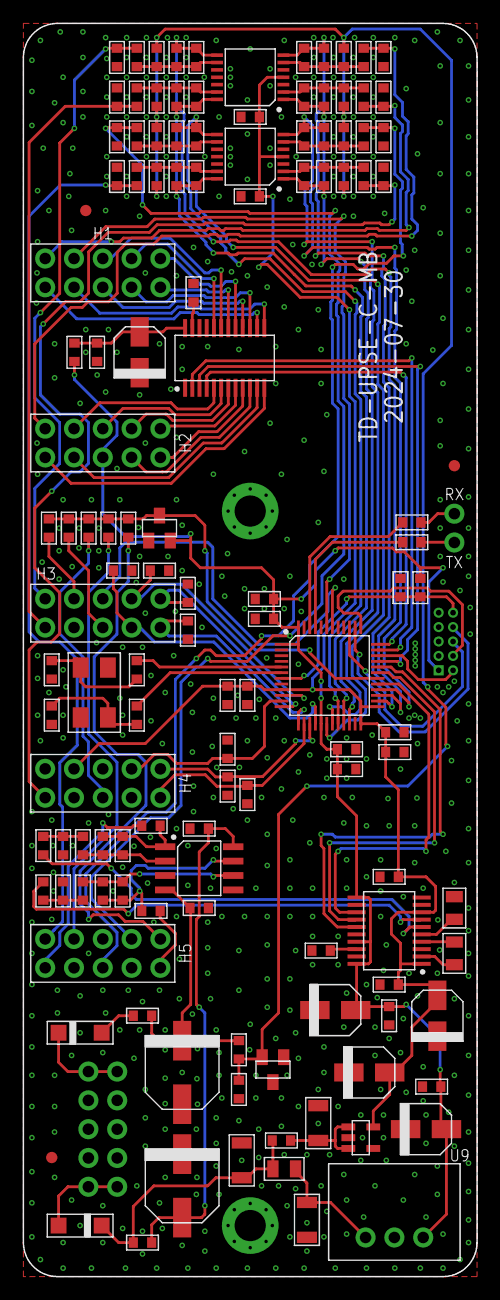
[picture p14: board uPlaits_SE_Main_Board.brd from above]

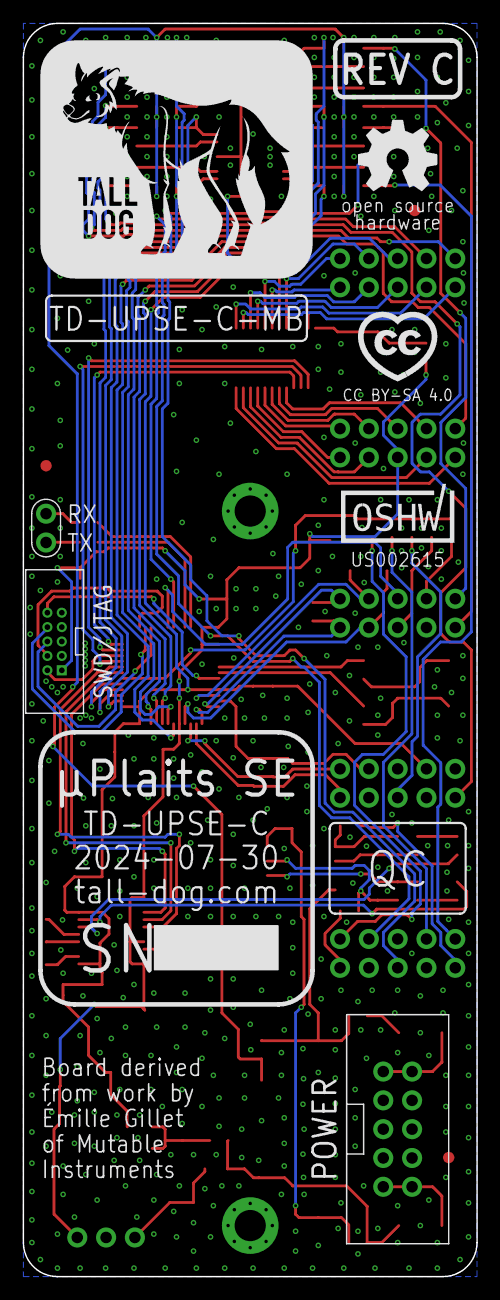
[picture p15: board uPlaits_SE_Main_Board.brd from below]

Board: 2 copper layers, 40.0 x 110.5 mm, 144 parts (11 on the bottom side), 102 nets.

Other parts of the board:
U$1: LOGO-TD
U$6, U$7, U$8: FIDUCIAL
U$9: LOGO-CC
U$10: LOGO-OSH
U$11: LOGO-OSHW
U$12: LOGO-PN
U$13: LOGO-QC
U$14: LOGO-REV
U$15: LOGO-SN

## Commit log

2021-03-23 Revision B
    [uPlaits_SE_Assembly_Cap.stl, uPlaits_SE_Assembly_Spacer.stl, uPlaits_SE_Assembly_Template.brd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]
2024-07-07 updates and cleanup for Rev C production run
    [uPlaits_SE_Assembly_Cap.step, uPlaits_SE_Assembly_Spacer.step, uPlaits_SE_Assembly_Spacer.stl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]
2024-07-07 changed Assembly Template to green for consistency
    [uPlaits_SE_Model.skp, uPlaits_SE_PCB_Specs.csv]
2024-07-13 small BOM correction
    [uPlaits_SE_Main_Board_BOM.csv]
2024-07-20 updated jack part number, added control board XYR, updated main board XYR slightly
    [uPlaits_SE_Control_Board_BOM.csv, uPlaits_SE_Control_Board_XYR.csv, uPlaits_SE_Main_Board_XYR.csv]
2024-08-08 revision C updates continued
    [uPlaits_SE_Control_Board.brd, uPlaits_SE_Control_Board.sch, uPlaits_SE_Control_Board_XYR.csv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]
